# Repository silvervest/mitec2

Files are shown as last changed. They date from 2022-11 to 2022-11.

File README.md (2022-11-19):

## Programming

I am using an el cheapo USB to FT232H UART adapter from AliExpress

### Pin connections

| JTAG | FTDI |
|---|---|
| TCK  | AD0  |
| TDI  | AD1  |
| TDO  | AD2  |
| TMS  | AD3  |
| VCC  | 3.3V |
| GND  | GND  |

### Steps

First we need to change the frequency line in the SVF file... The default 1MHz is too fast, so we're slowing it to 300KHz which seems to work fine.
```bash
$ sed -i "s/FREQUENCY 1E6 HZ/FREQUENCY 3E5 HZ/" mitec2.svf
```

Second we need to setup UrJTAG for the CPLD, but adding the xc9536xl_vq44 stepping to the configuration (you may need to change this file path depending on your install)
```bash
$ echo "0101    xc9536xl_vq44   5" | sudo tee -a /usr/local/share/urjtag/xilinx/xc9536xl/STEPPINGS
```

Finally, we can program
```bash
$ sudo jtag

UrJTAG 2021.03 #
Copyright (C) 2002, 2003 ETC s.r.o.
Copyright (C) 2007, 2008, 2009 Kolja Waschk and the respective authors

UrJTAG is free software, covered by the GNU General Public License, and you are
welcome to change it and/or distribute copies of it under certain conditions.
There is absolutely no warranty for UrJTAG.

warning: UrJTAG may damage your hardware!
Type "quit" to exit, "help" for help.

jtag> cable jtagkey vid=0x0403 pid=0x6014
Connected to libftdi driver.
jtag> detect
IR length: 8
Chain length: 1
Device Id: 01011001011000000010000010010011 (0x59602093)
  Manufacturer: Xilinx (0x093)
  Part(0):      xc9536xl (0x9602)
  Stepping:     5
  Filename:     /usr/local/share/urjtag/xilinx/xc9536xl/xc9536xl_vq44
jtag> svf hdl/mitec2.svf stop progress
detail: Parsing   5160/5163 ( 99%)detail: 
detail: Scanned device output matched expected TDO values.
jtag> 
```

If all went well, you will get the success message

`detail: Scanned device output matched expected TDO values.`

Your device is now programmed!

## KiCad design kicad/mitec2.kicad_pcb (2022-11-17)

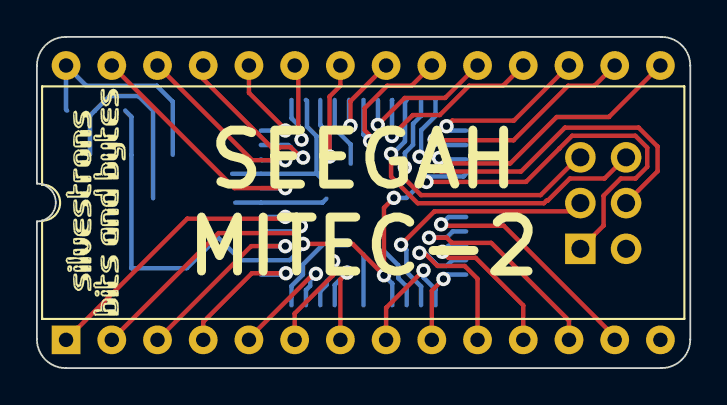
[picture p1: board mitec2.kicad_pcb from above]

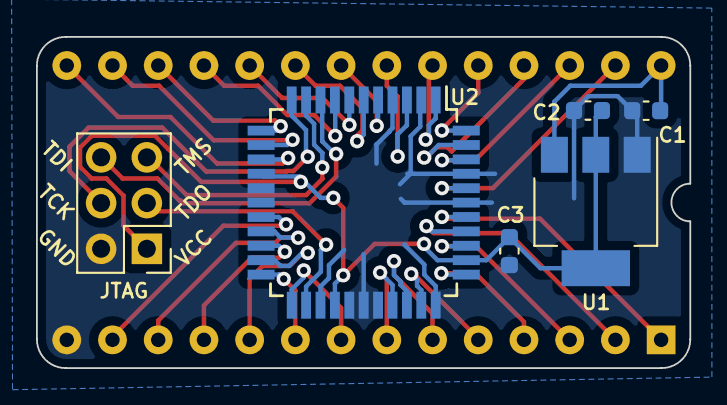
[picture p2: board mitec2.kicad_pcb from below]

Board: 2 copper layers, 36.3 x 18.4 mm, 7 parts (6 on the bottom side), 33 nets.

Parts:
C1, C2: 1uF; C_0603_1608Metric
C3: 100nF; C_0603_1608Metric
J1: MITEC2; DIP-28_W15.24mm_Socket
JTAG: JTAG; PinHeader_2x03_P2.54mm_Vertical
U1: AMS1117-3.3; SOT-223-3_TabPin2
U2: XC9536XL-10VQ44C; TQFP-44_10x10mm_P0.8mm

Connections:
+3V3: C2.1, C3.1, JTAG.1, U1.2 (VO), U2.15 (VCC), U2.26 (VCC), U2.35 (VCCIO)
+5V: C1.2, J1.28, U1.3 (VI)
/A6: J1.17, U2.12 (M13)
/A7: J1.18, U2.8 (M12)
/A14: J1.12, U2.19 (M17)
/A15: J1.13, U2.18 (M17)
/JTAG_TCK: JTAG.4, U2.11 (TCK)
/JTAG_TDI: JTAG.6, U2.9 (TDI)
/JTAG_TDO: JTAG.3, U2.24 (TDO)
/JTAG_TMS: JTAG.5, U2.10 (TMS)
/RAMA7: J1.19, U2.7 (M11)
/~CAS1: J1.23, U2.1 (M6)
/~CAS2: J1.24, U2.44 (I/O/GCK2)
/~CE89: J1.25, U2.43 (I/O/GCK1)
/~CEROM2: J1.16, U2.13 (M14)
/~CSR: J1.26, U2.42 (M4)
/~CSSRAM: J1.15, U2.14 (M15)
/~CSW: J1.27, U2.40 (M1)
/~IORQ: J1.6, U2.31 (M8)
/~IOR: J1.10, U2.21 (M16)
/~IOW: J1.11, U2.20 (M15)
/~MEMR: J1.8, U2.23 (M13)
/~MEMW: J1.9, U2.22 (M14)
/~MREQ: J1.2, U2.37 (M4)
/~MUX: J1.20, U2.6 (M10)
/~NMIN: J1.3, U2.36 (I/O/GTS1)
/~NMI: J1.1, U2.38 (M2)
/~RAS1: J1.21, U2.5 (M9)
/~RAS2: J1.22, U2.3 (M8)
/~RD: J1.4, U2.34 (I/O/GTS2)
/~RFSH: J1.7, U2.30 (M9)
/~WR: J1.5, U2.32 (M7)
GND: C1.1, C2.2, C3.2, J1.14, JTAG.2, U1.1 (GND), U2.2 (I/O/GCK3), U2.4 (GND), U2.16 (M16), U2.17 (GND), U2.25 (GND), U2.27 (M12), U2.28 (M11), U2.29 (M10), U2.33 (I/O/GSR), U2.39 (M1), U2.41 (M2)

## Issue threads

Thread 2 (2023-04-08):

CSSRAM and CEROM2 meanings. Patching?

siriokds, 2023-04-08:
CSSRAM is the chip select of onboard SRAM despite the ram size (could be up to 32KB if Sega engineers decided it).
It's correct to use MREQ (0) and A15 (1) signals. it is connected to /CS signal of the onboard 2KB SRAM chip and to /DSRAM (B3) signal of cartridge connector.

CEROM2 (a.k.a. "/8-B") is the signal/pin for the 0x8000-0xBFFF bank select. It should use MREQ (0), A15 (1) and A14 (0) combo.
Cartridges can use it for 48KB games (32KB rom + 16KB rom) or as memory mapped register area. It can be used for 16KB memory expansion as well (32KB cart rom + 16KB cart ram + 2KB onboard ram).

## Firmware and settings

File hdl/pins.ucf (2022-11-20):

NET "NMIN" LOC = "P36";
NET "RD" LOC = "P34";
NET "WR" LOC = "P32";
NET "MREQ" LOC = "P37";
NET "IORQ" LOC = "P31";
NET "RFSH" LOC = "P30";
NET "RAMA7" LOC = "P7";
NET "A6" LOC = "P12";
NET "A7" LOC = "P8";
NET "A14" LOC = "P19";
NET "A15" LOC = "P18";
NET "NMI" LOC = "P38";
NET "IOR" LOC = "P21";
NET "IOW" LOC = "P20";
NET "MEMR" LOC = "P23";
NET "MEMW" LOC = "P22";
NET "CSR" LOC = "P42";
NET "CSW" LOC = "P40";
NET "CE89" LOC = "P43";
NET "CSSRAM" LOC = "P14";
NET "CEROM2" LOC = "P13";
NET "CAS1" LOC = "P1";
NET "RAS1" LOC = "P5";
NET "CAS2" LOC = "P44";
NET "RAS2" LOC = "P3";
NET "MUX" LOC = "P6";
